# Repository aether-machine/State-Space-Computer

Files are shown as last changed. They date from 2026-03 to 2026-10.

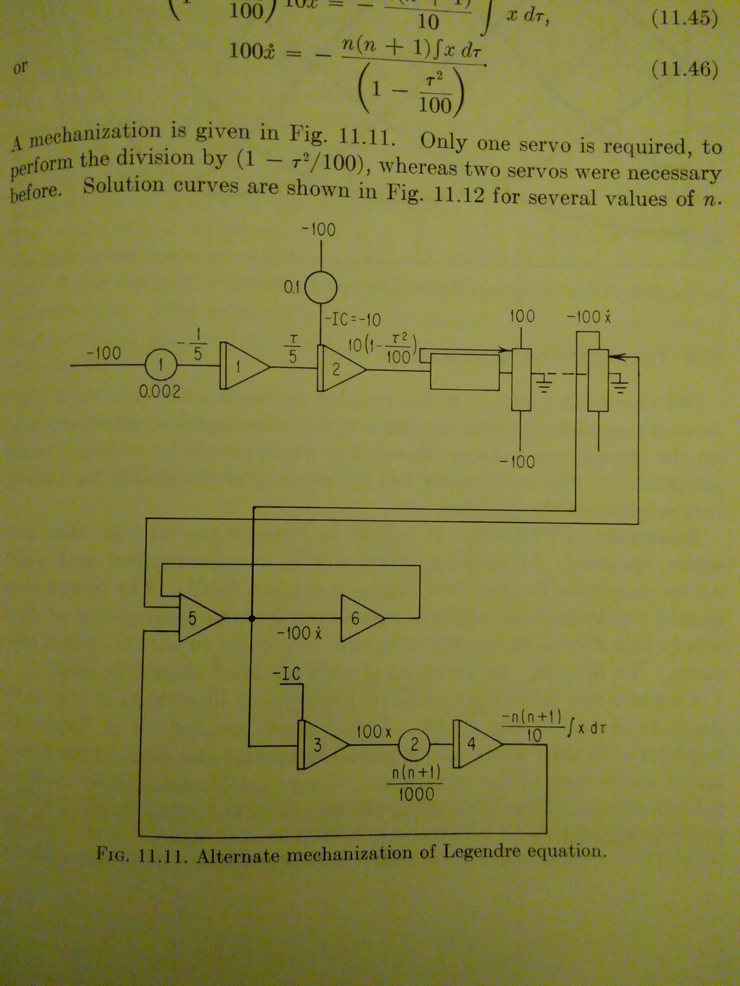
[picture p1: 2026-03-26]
img_20171024_1923181.jpg

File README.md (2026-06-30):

This repository began it's life as the Oscilloplasm module which existed for a brief time in the Wiard 300 Series format, and has now expanded into a complete and separate take on the audio synthesis paradigm based on continuous computing techniques that occur in the physical and non-physical domains. Here, we present both a general method to solve computing problems using electronic means, and ready made solutions to build and install yourself. The licensing is strictly for non-commercial use only, e.g. education, DIY.

The place to begin is the representation of physical phenomena as periodic information, starting in two dimensions as sound waves and following through into three dimensional particles as persistant standing wave patterns that make up our physical universe. This representation can be done in maths using differential equations, from simple linear ordinary differential equations (ODEs) that describe electron shell configurations, into complex non-linear partial differential equations (PDEs) that can describe motion in a body of water, likely with multiple flow velocities and different viscosities. At the most extreme form, a single equation might be able to describe the entire universe, for example reaction-diffusion equations can give rise to cell like growth.

The primitive in analog computing is the state variable, which appears in both the harmonic oscillator (sine wave) and the multimode filter. Mathematically:

$$
\frac{d^2x}{dt^2} + 2\gamma \frac{dx}{dt} + \omega^2 x = F(t)
$$

Where ω = 2πf is the angular frequency of the sine wave and the first derivative x' controls damping or growth. To solve in analog form, the second differential x'' (with respect to time) is passed through two voltage controlled integrators, each comprised of a variable transconductance stage, an opamp and a capacitor as a memory cell, with the inversion of the x output connected to the input to solve. This is the general form of solving ODEs using electronic means, to re-arrange in terms of the lowest order derivative, assume that it exists, and then solve by parts using cascaded integrator stages, the final integrator stage then represents the solution and this is used as the input to complete the cycle.

The harmonic oscillator circuit here is unique to the system, a self stablizing sine wave based around a trig identity for instant in the loop gain correction:

$$
sin^2 + cos^2 - 1 = 0
$$

Using two Gilbert Cell mulitpliers and a zener diode stabilized DC reference, this generates a real time error value which can be used to modulate the oscillator loop gain and maintain long term amplitude stability, as well as two second harmonic outputs for the sine and cosine portions of the waveform. The complete equation with stabilization is:

$$
\frac{d^2 x}{dt^2} + 2k\epsilon \frac{dx}{dt} + \left(\omega^2 + k^2\epsilon^2\right)x = 0
$$

Output oscillator is a variable harmonic wavetable that solves Legendre's Ordinary Differential Equation in real time:

$$
(1 - t^2) \frac{d^2x}{dt^2} - 2t \omega \frac{dx}{dt} + (\omega^2 - l(l+1))x = 0
$$

Where L represents the azimuthal quantum number, thus generating polynomial functions in a completely novel (and sometimes frustrating) way.

The stabilization technique in this oscillator is also state of the art, although there is a compromise between harmonic distortion and ampltiude distortion. Ampltitude distortion as the RMS to DC converter gets stuck in a modulation loop is probably the more destructive force here for audio work. It can be mitigated by avoiding rapid changes in oscillator frequency, perhaps by using a slew limiter on your seqeuncer.

Output oscillator uses four quadrant multipliers and is designed for through zero behaviour.



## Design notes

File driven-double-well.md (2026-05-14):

# Driven Double-Well Circuit for Audio-Rate Analog Synthesis

This project explores audio-rate analog synthesis by directly implementing a nonlinear dynamical system in hardware.

The circuit is a physical analog realization of a driven double-well system related to the Duffing equation. Rather than starting from a conventional oscillator waveform and shaping it afterward, the circuit solves the system continuously in real time using integrators, summers, transconductance stages, and analog multipliers.

In this sense, the circuit is both a sound source and a small analog computer.

Governing equation

A normalized form of the system is:

$$x^{\prime\prime} + b x^\prime - x + x^3 = E(t)$$

where:

x is the state variable
b is the damping coefficient
−x+x
3
 defines the double-well restoring force
E(t) is the external drive term

This sign structure is important. The negative linear term and positive cubic term create a double-well potential, in contrast to the single-well behavior of the harmonic oscillator.

Analog computing approach

The general method is to rearrange the differential equation in terms of the lowest-order derivative to be solved directly, then realize the system with cascaded integrator stages.

For a second-order equation such as

$$x^{\prime\prime} + b x^\prime - x + x^3 = E(t)$$

we rearrange to isolate the highest derivative:

$$x^{\prime\prime} = -b x^\prime + x - x^3 + E(t)$$

This is then split into a pair of first-order state equations. For example, defining

$$x^\prime = y$$

gives

$$x^\prime = y$$
$$y^\prime = -b y + x - x^3 + E(t)$$

These state equations are well suited to analog implementation:

one integrator solves x
′
=y
a second integrator solves y
′
=−by+x−x
3
+E(t)
a summing stage forms the right-hand side
a nonlinear block generates the cubic term x
3

The circuit therefore computes the evolving state trajectory directly in continuous time.

Circuit structure

The present implementation uses:

LM13700 OTA stages for integrator transconductance
TL072 / LT1057 op amps for summing, buffering, and integration
analog multipliers to generate the cubic nonlinearity
separate feedback paths for:
linear restoring term
cubic restoring term
damping
external drive

At the block level the architecture is:

State integrator 1
Produces one system state from the other.
State integrator 2
Integrates the summed force term.
Nonlinear block
Generates the cubic term x
3
, typically by squaring x and multiplying again by x.
Damping path
Feeds back the velocity-like state with adjustable coefficient.
Drive input
Injects external forcing into the summing node.
Why this is different from conventional subtractive synthesis

Most analog synthesizers are built around a stable oscillator-plus-filter model. This circuit belongs to a different category.

Here, the sound is generated by the real-time solution of a nonlinear differential equation. Parameters such as:

damping
drive level
drive frequency

do not simply shape tone after the fact; they alter the qualitative behavior of the system itself.

Depending on parameter settings, the circuit can exhibit:

motion confined to one well
periodic transitions between wells
irregular switching
chaotic behavior

The output is therefore better understood as the observed behavior of a dynamical system than as a conventional oscillator waveform.

Project status

This repository is currently incomplete.

At present:

the circuit has been prototyped and tested on veroboard / protoboard
the main control loop and nonlinear structure are working
the full KiCad project is not yet finalized
some auxiliary details are still being cleaned up for publication, including:
input scaling
bias/current details for OTA stages
multiplier support nodes and scaling conventions
final schematic organization

The complete KiCad files will be added later.

Notes on implementation

A few practical observations from the current build:

The double-well behavior depends critically on the sign of the restoring-force terms.
The linear and cubic terms must resolve to the equivalent of:
-x + x^3

in the normalized equation.

The damping term acts independently of the nonlinear restoring block and sets the effective coefficient of x
′
.
In multiplier-based implementations, intermediate squaring stages may exhibit DC components, but the final cubic term is odd and ideally does not introduce a net offset by itself.
In practice, offsets and asymmetries can still arise from multiplier feedthrough, op-amp offset, OTA mismatch, and grounding/layout effects.
Repository contents

Planned contents include:

schematic files
board/prototype photos
block-diagram explanation
derivation from differential equation to state-variable form
implementation notes on signs, scaling, and nonlinear synthesis
example audio and scope traces
Motivation

The broader aim of this work is to explore analog synthesis as a subset of analog computation.

Conventional oscillator/filter architectures remain important, but they do not exhaust the range of continuous-time systems that can operate as sound-generating circuits. Nonlinear state-space circuits such as the driven double-well system suggest a wider design space for analog musical instruments.

Disclaimer

This is an experimental hardware project. The present repository documents a working prototype and the underlying method, but not yet a finalized production design.

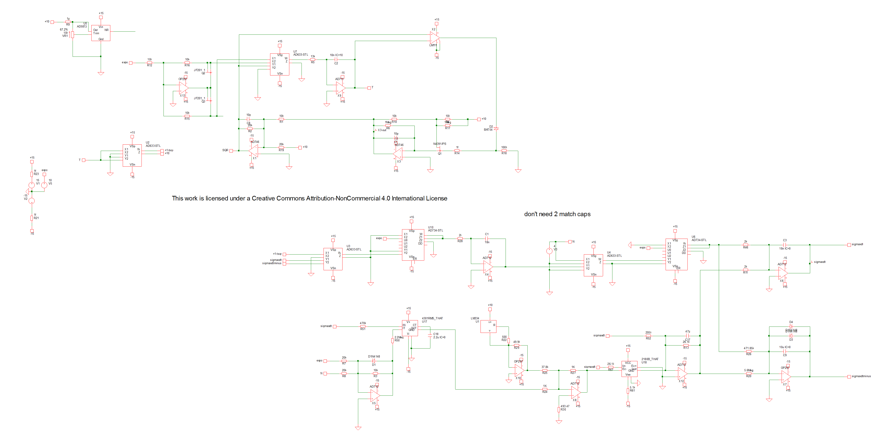
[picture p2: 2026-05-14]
Oscilloplasm-VCOs/legendre-again51.png

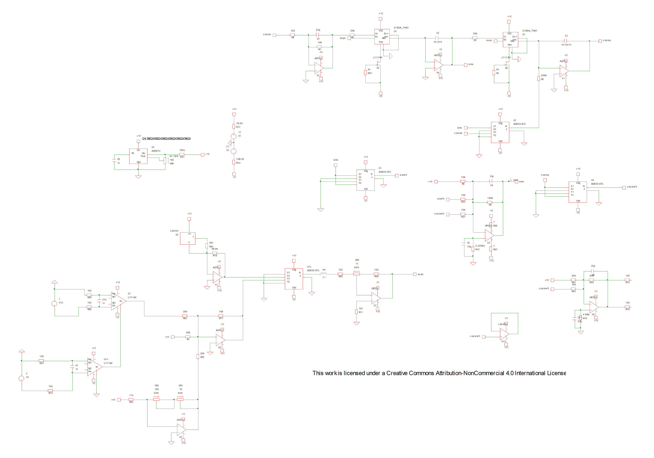
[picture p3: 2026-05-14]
Oscilloplasm-VCOs/sine281.png

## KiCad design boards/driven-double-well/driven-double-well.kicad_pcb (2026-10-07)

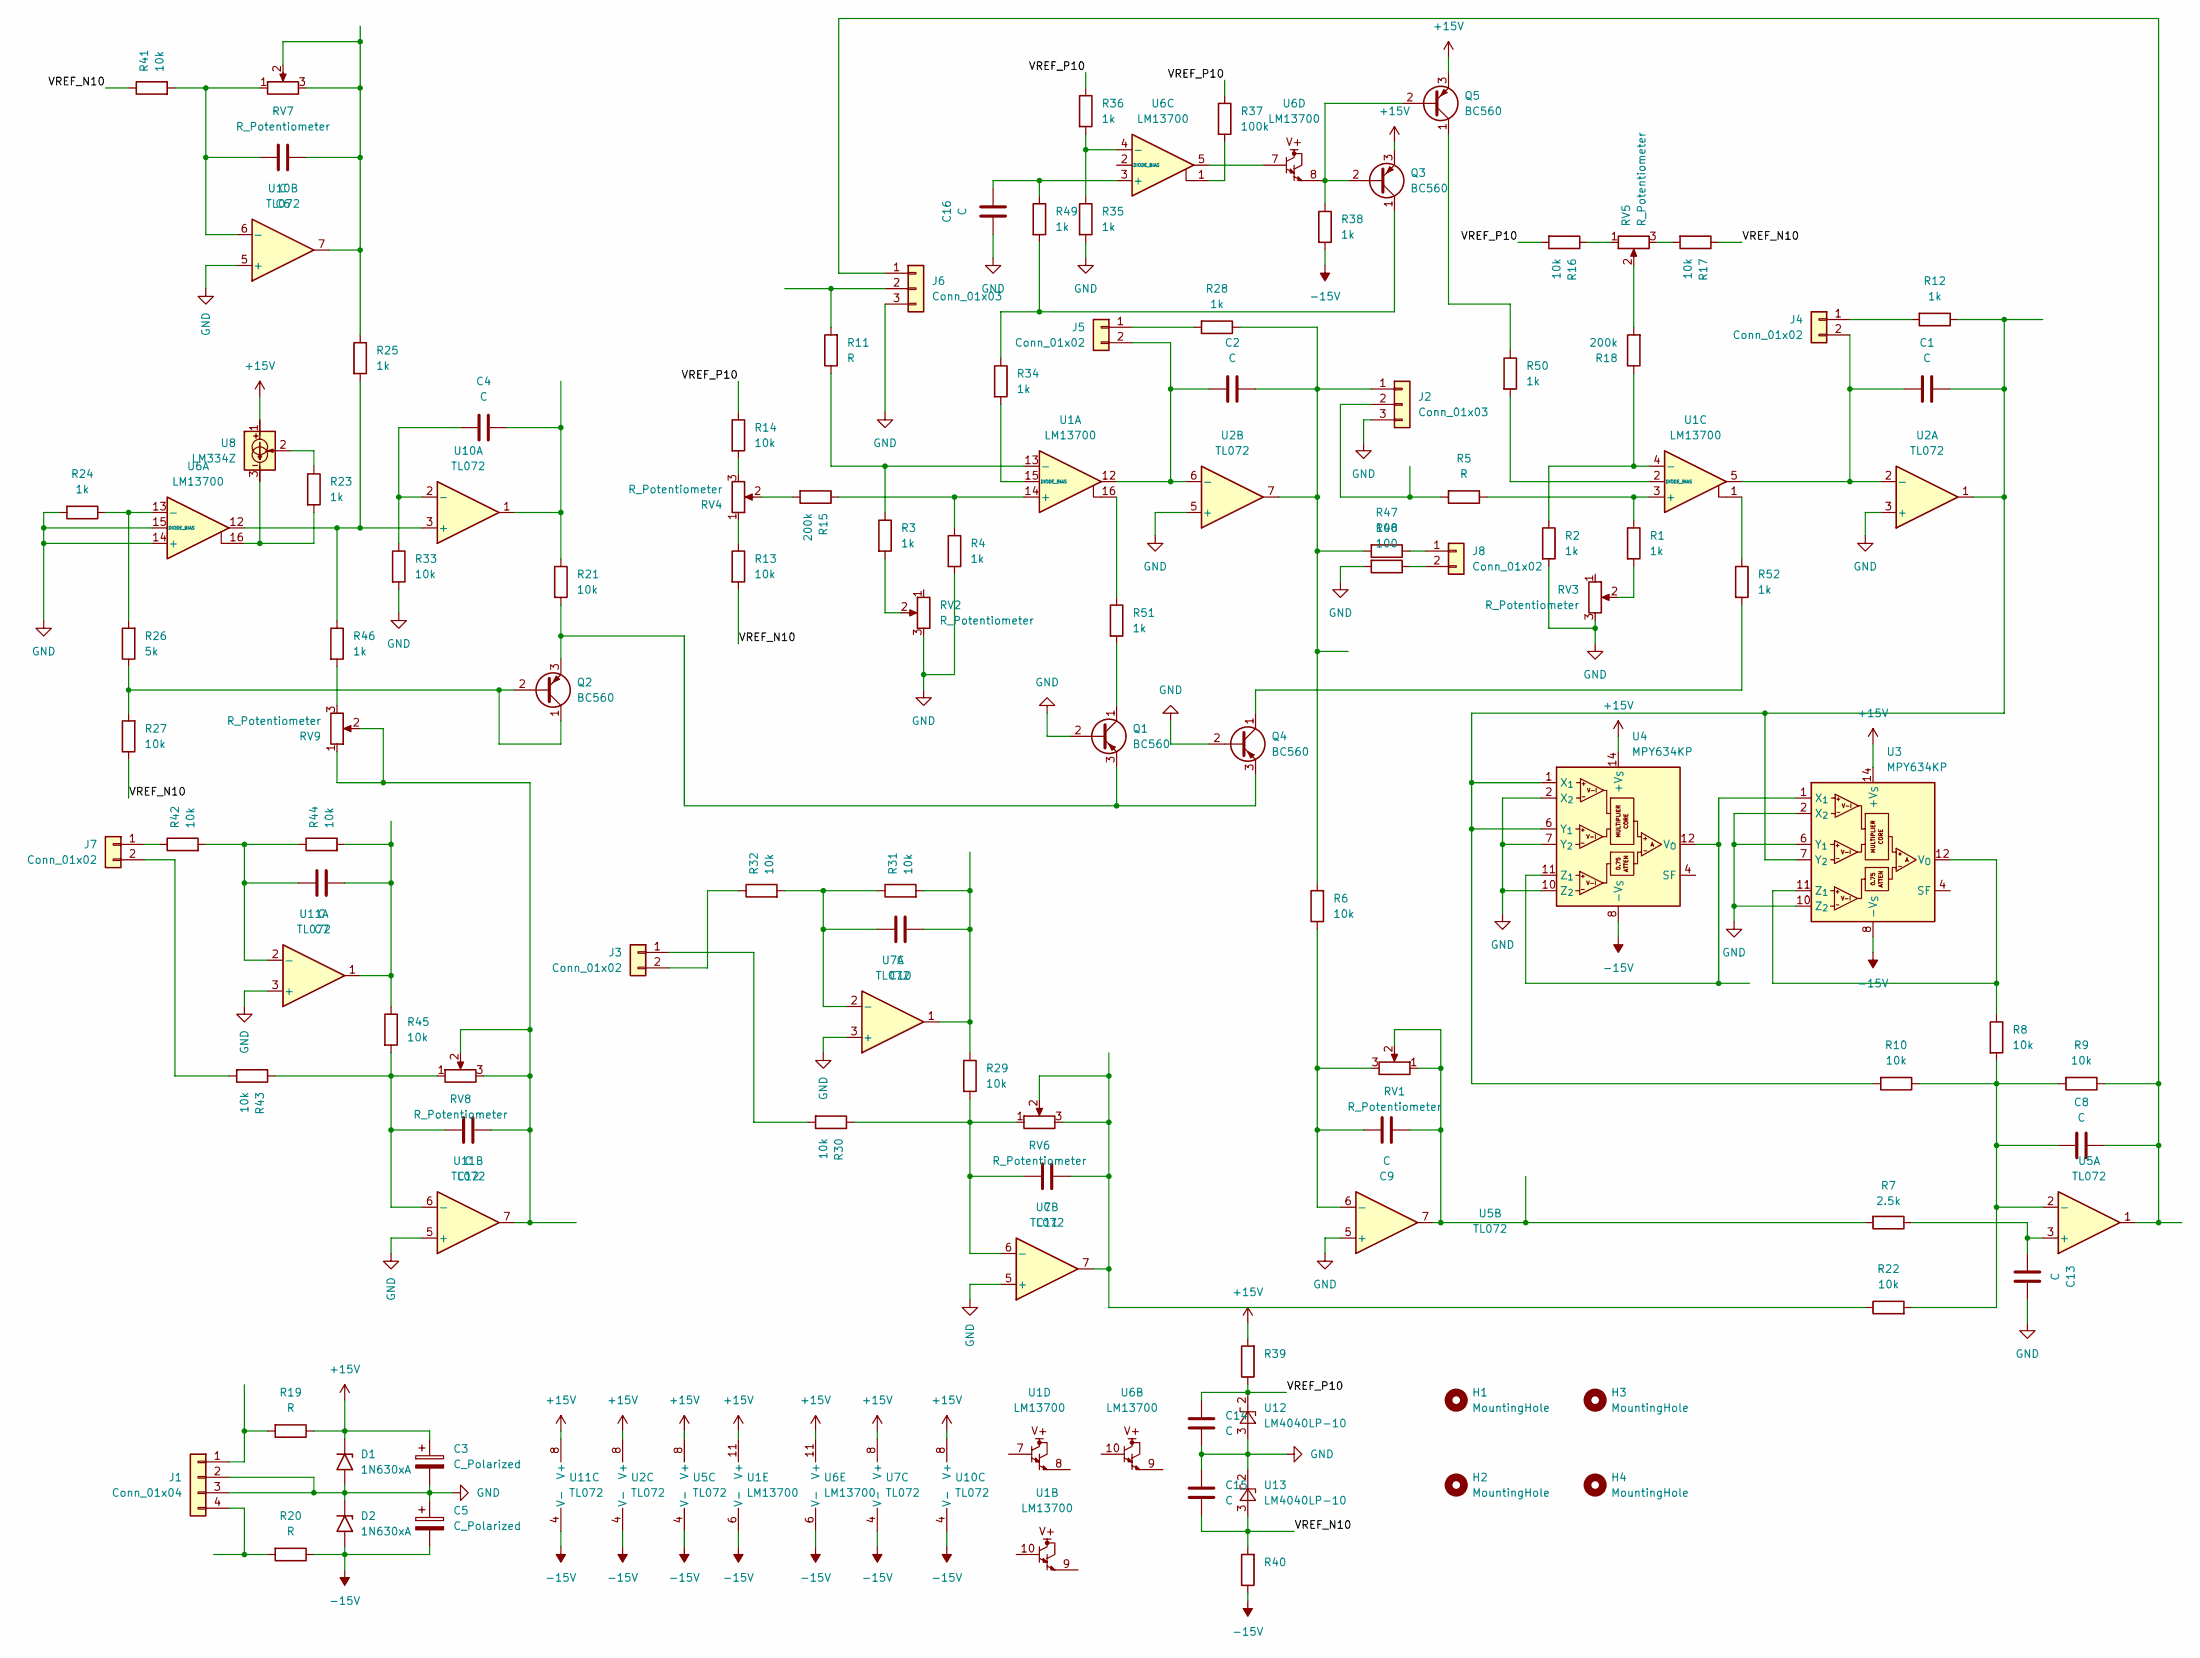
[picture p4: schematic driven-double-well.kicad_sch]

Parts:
C1, C2: C; C_Axial_L17.0mm_D7.0mm_P20.00mm_Horizontal
C3, C5: C_Polarized; CP_Radial_D8.0mm_P5.00mm
C4, C7, C8, C9, C10, C11, C13: C; C_Disc_D3.4mm_W2.1mm_P2.50mm
C6, C12, C16: C; C_Rect_L7.2mm_W2.5mm_P5.00mm_FKS2_FKP2_MKS2_MKP2
C14, C15: C; C_Rect_L7.2mm_W4.5mm_P5.00mm_FKS2_FKP2_MKS2_MKP2
D1, D2: 1N630xA; D_DO-201AE_P12.70mm_Horizontal
H1, H2, H3, H4: MountingHole; MountingHole_3.2mm_M3
J1: Conn_01x04; Molex_KK-396_A-41791-0004_1x04_P3.96mm_Vertical
J2, J6: Conn_01x03; PinHeader_1x03_P2.54mm_Vertical
J3, J7, J8: Conn_01x02; Molex_KK-254_AE-6410-02A_1x02_P2.54mm_Vertical
J4, J5: Conn_01x02; PinHeader_1x02_P2.54mm_Vertical
Q1, Q2, Q3, Q4, Q5: BC560; TO-92_HandSolder
R1, R2, R3, R4, R12, R23, R24, R25, R28, R34, R35, R36, R38, R46, R49, R50, R51, R52: 1k; R_Axial_DIN0207_L6.3mm_D2.5mm_P10.16mm_Horizontal
R5, R11: R; R_Axial_DIN0207_L6.3mm_D2.5mm_P10.16mm_Horizontal
R6, R8, R9, R10, R13, R14, R16, R17, R21, R22, R27, R29, R30, R31, R32, R33, R41, R42, R43, R44, R45: 10k; R_Axial_DIN0207_L6.3mm_D2.5mm_P10.16mm_Horizontal
R7: 2.5k; R_Axial_DIN0207_L6.3mm_D2.5mm_P10.16mm_Horizontal
R15, R18: 200k; R_Axial_DIN0207_L6.3mm_D2.5mm_P10.16mm_Horizontal
R19, R20: R; R_Axial_DIN0414_L11.9mm_D4.5mm_P15.24mm_Horizontal
R26: 5k; R_Axial_DIN0207_L6.3mm_D2.5mm_P10.16mm_Horizontal
R37: 100k; R_Axial_DIN0207_L6.3mm_D2.5mm_P10.16mm_Horizontal
R39, R40: R_Axial_DIN0207_L6.3mm_D2.5mm_P10.16mm_Horizontal
R47, R48: 100; R_Axial_DIN0207_L6.3mm_D2.5mm_P10.16mm_Horizontal
RV1, RV6, RV7, RV8: R_Potentiometer; Molex_KK-254_AE-6410-03A_1x03_P2.54mm_Vertical
RV2, RV3, RV4, RV5, RV9: R_Potentiometer; Potentiometer_Bourns_3296Y_Vertical
U1, U6: LM13700; DIP-16_W7.62mm_Socket_LongPads
U2, U5, U7, U10, U11: TL072; DIP-8_W7.62mm_Socket_LongPads
U3, U4: MPY634KP; DIP-14_W7.62mm_Socket_LongPads
U8: LM334Z; TO-92_HandSolder
U12, U13: LM4040LP-10; TO-92_Inline

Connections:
+15V: C3.1, D1.1 (A1), Q3.3 (E), Q5.3 (E), R19.1, R39.2, U1.11 (V+), U2.8 (V+), U3.14 (+V_{S}), U4.14 (+V_{S}), U5.8 (V+), U6.11 (V+), U7.8 (V+), U8.1, U10.8 (V+), U11.8 (V+)
-15V: C5.2, D2.2 (A2), R20.1, R38.2, R40.1, U1.6 (V-), U2.4 (V-), U3.8 (-V_{S}), U4.8 (-V_{S}), U5.4 (V-), U6.6 (V-), U7.4 (V-), U10.4 (V-), U11.4 (V-)
/VREF_N10: C15.2, R13.2, R17.1, R27.1, R40.2, R41.1, U13.3 (A)
/VREF_P10: C14.1, R14.1, R16.2, R36.1, R37.1, R39.1, U12.2 (K)
GND: C3.2, C5.1, C13.1, C14.2, C15.1, C16.1, D1.2 (A2), D2.1 (A1), J1.2, J1.3, J2.3, J6.3, Q1.2 (B), Q4.2 (B), R2.2, R4.2, R24.2, R33.2, R35.2, R48.2, RV2.3, RV3.3, U2.3 (+), U2.5 (+), U3.2 (X_{2}), U3.6 (Y_{1}), U3.10 (Z_{2}), U4.2 (X_{2}), U4.7 (Y_{2}), U4.10 (Z_{2}), U5.5 (+), U6.14 (+), U6.15 (DIODE_BIAS), U7.3 (+), U7.5 (+), U10.5 (+), U11.3 (+), U11.5 (+), U12.3 (A), U13.2 (K)
unnamed: C4.1, R21.1, U10.1
unnamed: C6.1, R25.1, RV7.2, RV7.3, U10.7
unnamed: C7.1, R44.2, R45.1, U11.1
unnamed: C9.1, R7.2, RV1.1, RV1.2, U5.7
unnamed: C10.1, R29.1, R31.2, U7.1
unnamed: C11.1, R22.1, RV6.2, RV6.3, U7.7
unnamed: C12.1, RV8.2, RV8.3, RV9.1, RV9.2, U11.7
unnamed: J1.1, R19.2
unnamed: J1.4, R20.2
unnamed: C2.1, J2.1, R6.2, R28.1, R47.2, U2.7
unnamed: J2.2, R5.2
unnamed: J3.1, R30.2
unnamed: J3.2, R32.1
unnamed: J4.1, R12.2
unnamed: C1.2, J4.2, U1.5, U2.2 (-)
unnamed: J5.1, R28.2
unnamed: C2.2, J5.2, U1.12, U2.6 (-)
unnamed: C8.1, J6.1, R9.1, U5.1
unnamed: J6.2, R11.2
unnamed: J7.1, R42.1
unnamed: J7.2, R43.2
unnamed: J8.1, R47.1
unnamed: J8.2, R48.1
unnamed: Q1.1 (C), R51.2
unnamed: Q1.3 (E), Q2.3 (E), Q4.3 (E), R21.2
unnamed: Q2.1 (C), Q2.2 (B), R26.1, R27.2
unnamed: Q3.2 (B), Q5.2 (B), R38.1, U6.8
unnamed: Q3.1 (C), R34.1, R49.2
unnamed: Q4.1 (C), R52.2
unnamed: Q5.1 (C), R50.1
unnamed: R1.2, RV3.2
unnamed: R3.2, RV2.2
unnamed: R13.1, RV4.1
unnamed: R14.2, RV4.3
unnamed: R15.2, RV4.2
unnamed: R16.1, RV5.1
unnamed: R17.2, RV5.3
unnamed: R18.2, RV5.2
unnamed: R23.1, U8.2
unnamed: R23.2, U6.16, U8.3
unnamed: R37.2, U6.1
unnamed: R46.2, RV9.3
unnamed: R51.1, U1.16
unnamed: R52.1, U1.1
unnamed: R4.1, R15.1, U1.14 (+)
unnamed: R3.1, R11.1, U1.13 (-)
unnamed: R34.2, U1.15 (DIODE_BIAS)
unnamed: R1.1, R5.1, U1.3 (+)
unnamed: R2.1, R18.1, U1.4 (-)
unnamed: R50.2, U1.2 (DIODE_BIAS)
unnamed: R8.1, U3.11 (Z_{1}), U3.12 (V_{O})
unnamed: U3.1 (X_{1}), U4.11 (Z_{1}), U4.12 (V_{O})
unnamed: C1.1, R10.2, R12.1, U2.1, U3.7 (Y_{2}), U4.1 (X_{1}), U4.6 (Y_{1})
unnamed: C13.2, R7.1, U5.3 (+)
unnamed: C8.2, R8.2, R9.2, R10.1, R22.2, U5.2 (-)
unnamed: C9.2, R6.1, RV1.3, U5.6 (-)
unnamed: U6.5, U6.7
unnamed: R24.1, R26.2, U6.13 (-)
unnamed: C16.2, R49.1, U6.3 (+)
unnamed: R35.1, R36.2, U6.4 (-)
unnamed: C10.2, R31.1, R32.2, U7.2 (-)
unnamed: C11.2, R29.2, R30.1, RV6.1, U7.6 (-)
unnamed: R25.2, R46.1, U6.12, U10.3 (+)
unnamed: C4.2, R33.1, U10.2 (-)
unnamed: C6.2, R41.2, RV7.1, U10.6 (-)
unnamed: C7.2, R42.2, R44.1, U11.2 (-)
unnamed: C12.2, R43.1, R45.2, RV8.1, U11.6 (-)

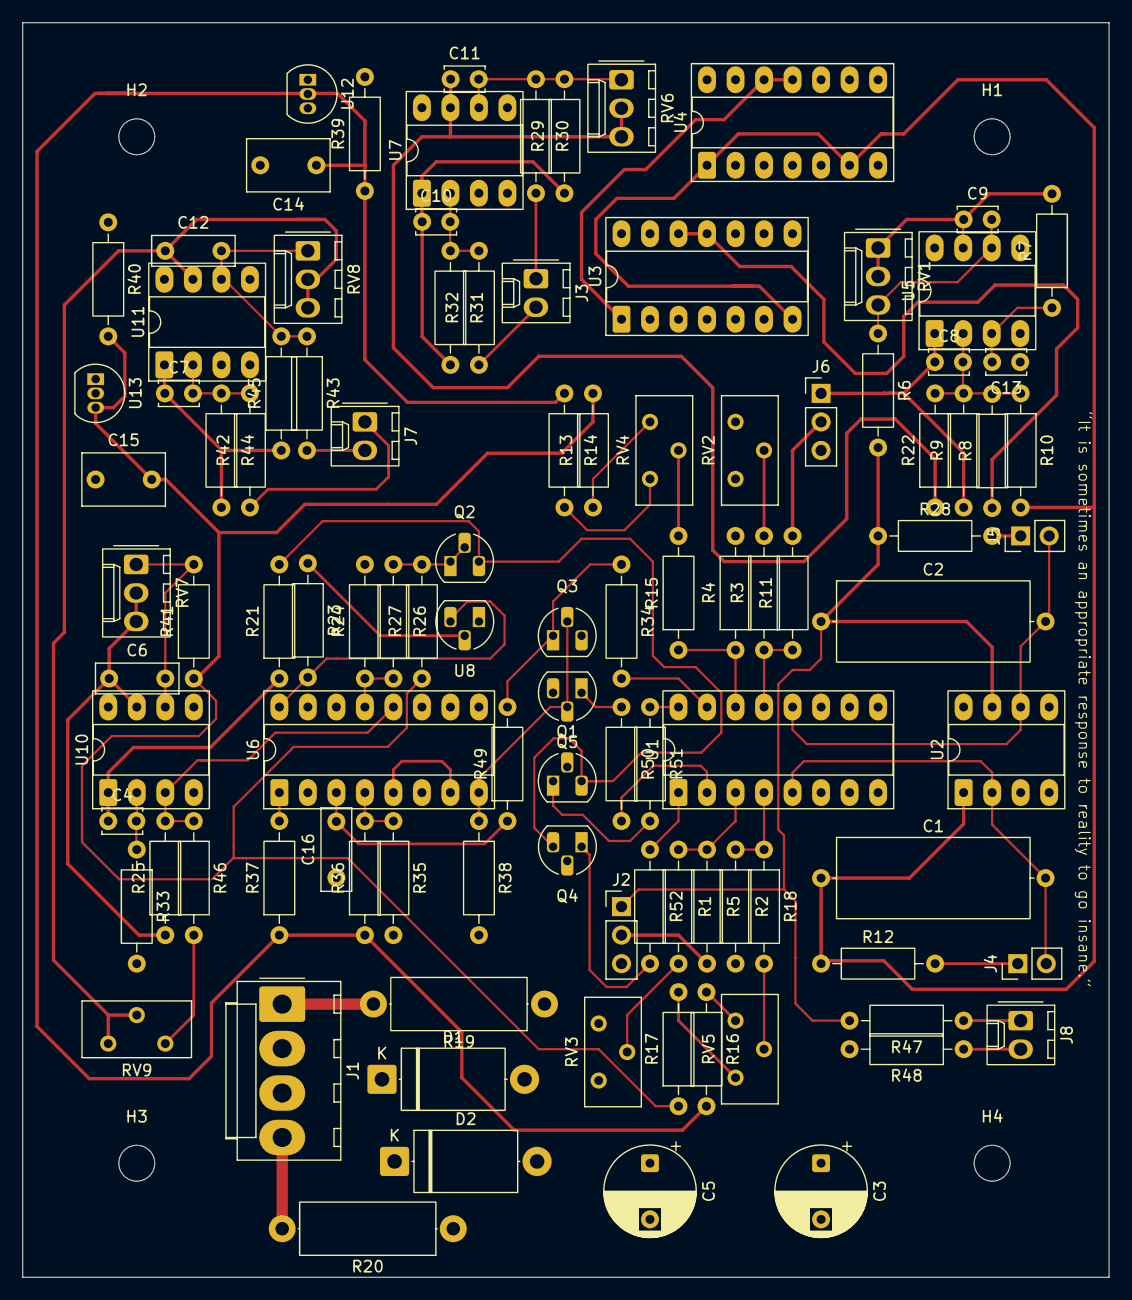
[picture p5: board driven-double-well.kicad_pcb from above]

Board: 4 copper layers, 96.8 x 111.8 mm, 108 parts (0 on the bottom side), 72 nets.

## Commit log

2026-10-07 Add driven double well board (#1)
    [driven-double-well.kicad_pcb, driven-double-well.kicad_sch]
2026-10-13 Update driven double well board (#2)
